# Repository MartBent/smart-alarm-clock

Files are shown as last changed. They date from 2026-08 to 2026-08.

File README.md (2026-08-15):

# Smart Alarm Clock

A bedside alarm clock built from scratch: custom hardware, firmware in Rust on an
ESP32-S3, and a Home Assistant integration. The idea is a plain wood-veneer bar that
stays dark until you touch it, then shows the time glowing through the veneer. It sits
on the network and works with Home Assistant, but it keeps its own time and fires
alarms itself, so it still rings if WiFi or HA goes down.

Right now it runs on a breadboard. The firmware and the HA integration work; the
custom PCB and the veneer enclosure are still ahead.

## Layout

| Path | What it is |
|---|---|
| `software/firmware/` | Rust (esp-idf) firmware for the device. See [software/README.md](software/README.md). |
| `software/homeassistant/` | Home Assistant integration. It now lives in its own HACS repo; this folder is a pointer. See [README](software/homeassistant/README.md). |
| `software/tools/` | `sim_device.py`, a stand-in for the device over REST + SSE. |
| `hardware/` | PCB, enclosure, and the bench parts list + wiring. See [hardware/README.md](hardware/README.md). |
| `docs/` | Design decisions and the reasoning behind them. See [handoff.md](docs/handoff.md). |

## Hardware

An ESP32-S3 drives a monochrome dot-matrix that shows the time behind wood veneer.
Touch is the ESP32-S3's built-in capacitive sensing through a foil pad, which reads
fine through wood. A DS3231 keeps time while the network is down; on the PCB a
supercap backs it up, so there's no coin cell. Sound is a passive buzzer for now. The
whole thing runs off USB-C, no battery.

It's on a breadboard at the moment. The parts list, wiring, and PCB plan are in
[hardware/README.md](hardware/README.md).

## Software

The firmware is a handful of worker threads around one shared state machine. The
alarm core owns the clock and the eight alarm slots and decides when to ring; nothing
about firing depends on the network. There's an on-device web UI with a WiFi captive
portal for first-time setup, and two ways into Home Assistant: MQTT discovery, and a
broker-free integration that uses the REST API with SSE for live updates. A small
Python simulator stands in for the hardware so the HA side can be worked on without a
device.

Build and flash steps, the thread layout, and the HA details are in
[software/README.md](software/README.md).

## Design

The locked decisions and why they were made are in [docs/handoff.md](docs/handoff.md).

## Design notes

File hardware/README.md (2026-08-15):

# Hardware

The custom PCB and enclosure, plus the breadboard bench validation that has to pass
before either gets built. The bench board so far is a YD-ESP32-S3 devkit
(ESP32-S3-WROOM-1). The reasoning behind the design choices is in
[`../docs/handoff.md`](../docs/handoff.md).

## Components (v1)

- MCU: ESP32-S3-WROOM-1 with native USB-JTAG. Bench board is a YD-ESP32-S3 devkit.
- Time: SNTP, with a DS3231 RTC and a supercap for backup. No coin cell.
- Power: USB-C mains, 5 V stepped down to 3.3 V. The supercap only backs the RTC.
- Display: a monochrome dot-matrix showing the time, behind wood veneer, dark when
  idle. The bench uses a red MAX7219 32×8; the final panel will be a warm/amber
  emitter picked at the PCB stage. Status (armed, ringing, and so on) shows on the
  onboard WS2812 RGB LED.
- Interaction: the ESP32-S3's built-in capacitive touch, a foil or copper pad behind
  the veneer with a tap/hold grammar. It reads through wood, which sidesteps the
  IR-through-veneer problem. Rear buttons are available too.
- Audio: a passive buzzer driven by LEDC/PWM through a BS170 low-side switch. Real
  audio is a possible later addition (see below).

## Bench validation

The point of this stage is to get the whole device working on a breadboard before
committing to a PCB. Each part below already has a firmware hook, or is the next
thing to wire. It uses the dev board and buttons already on hand. Sourcing is EU
(Tinytronics, Antratek, AliExpress); the prices are rough guides.

### Parts

Everything came from Tinytronics except the veneer (and, later, the copper tape).

| Part | Serves | Firmware hook | ~€ |
|---|---|---|---|
| **LED Matrix 32×8 with MAX7219** (red, 3-wire SPI-like; SKU 003516) | shows `HH:MM` (time only) — validate 4-digit layout/legibility/geometry behind veneer | matrix time render (to wire) | 6 |
| **Keyestudio DS3231 RTC** module (I²C, SKU 005849) | correct time on boot + offline alarm firing | RTC read/set fallback (scaffolded) | 4 |
| **Passive Buzzer 3-12V — Dupont-Jumper** (passive → PWM tones) | v1 wake sound | LEDC/PWM (`buzzer.rs`) | 1 |
| **4-channel Bi-Directional Logic Level Converter** (3.3↔5 V, BSS138) | reliable data into the 5 V MAX7219 from 3.3 V ESP32 | — | 1.5 |
| **Capacitive-touch electrode** — kitchen foil / jumper (proper copper tape later, *not* at Tinytronics) | tap + hold gestures via the ESP32-S3's **native** touch peripheral, no sensor chip | touch → `Command` bus (to wire) | ~0 |
| **Wood veneer sample pack** (~0.6 mm; walnut/oak/etc.) — *source elsewhere* | display glow-through look **and** capacitive-touch-through-veneer tuning | — | 5–10 |
| Decoupling caps (100 nF / 10 µF) | supporting | — | 2 |
| *Optional:* single **SK6812 / WS2812** discrete pixel | final placement of the RGB status LED (onboard WS2812 covers the bench) | already driven in `led.rs` | 1–2 |
| *Optional:* **Logic Analyzer 8-channel USB** | SPI/I²C bring-up debugging (sigrok/PulseView) | — | 9.75 |

The core is about €12.50 (matrix, RTC, buzzer, level converter), plus roughly €10 for
the optional logic analyzer. It's worth ordering a spare matrix and a spare level
converter. They don't wear out, but a wiring slip in the mixed 3.3/5 V path is easy to
make, and a reorder's shipping and wait cost more than the part does.

Status (2026-07-27): the electronics arrived; the veneer still needs sourcing. The
buzzer firmware is written. Breadboard bring-up was waiting on a soldering iron to
attach the dev-board header.

### Wiring

Every signal lands on the YD-ESP32-S3 power-side header (the `5Vin` / `3V3` / `RST`
row), so one soldered header covers the whole bench. The pin table below is the logical
reference (what connects to what), not a physical breadboard layout. The same
connections, drawn as a schematic, live under
[PCB and enclosure](#pcb-and-enclosure-after-bench-validation).

| Function | Pin | Notes |
|---|---|---|
| Buzzer | `GPIO4` | LEDC PWM → BS170 gate (low-side switch); internal pulldown, no external resistor |
| RTC SDA / SCL | `GPIO8` / `GPIO9` | I²C; **power the DS3231 at 3.3 V** (pull-ups reference VCC); scan should ACK at `0x68` |
| Matrix CS / DIN / CLK | `GPIO10` / `GPIO11` / `GPIO12` | native FSPI pins; **5 V logic** → drive through the level shifter |
| Cap touch | `GPIO14` | foil electrode; **no pull resistor** (interferes with sensing) |
| Power | `5Vin` / `3V3` / `GND` | `5Vin` = USB VBUS (5 V out when USB-powered); matrix VCC on `5Vin`, keep brightness modest |

A few things worth watching:

- Check the BS170's Drain and Source against your part's datasheet. The pinout is
  manufacturer-dependent (BS170 and 2N7000 are mirror images), and swapping D/S is the
  classic "won't switch" bug.
- Avoid `GPIO46` (LOG) and `GPIO3` (JTAG) on that header; both are strapping pins.
- The onboard WS2812 status LED is `GPIO48`, on the opposite header, left free for the
  phase-color LED.
- No loose resistors are needed: the module pull-ups and the BS170's internal gate
  pulldown cover it.
- If capacitive touch feels wrong, the fallback is a GY-APDS-9900 IR-reflective
  proximity module (I²C, about €3.50), which brings the IR-through-veneer test back.

### Bring-up sequence

1. Solder the dev-board header, then bring up the peripherals one at a time: RTC (I²C
   scan → `0x68`), buzzer, MAX7219 `HH:MM` render, capacitive touch. Prove the `HH:MM`
   glow, touch-through-veneer, and the warm look before a PCB.
2. Flesh out the firmware on the breadboard: RTC read, matrix render, touch input and
   tuning, NVS persistence.
3. KiCad schematic → ERC → 2-layer layout → DRC → Gerbers → order.
4. Bring up the bare board incrementally; iterate the veneer enclosure.

### Deferred to the PCB stage (the bench uses the simpler thing)

- RTC backup with a supercap instead of a coin cell. The supercap goes on the DS3231
  VBAT pin (across the coin-cell pads), not VCC — VBAT is the low-power (~1 µA) backup
  input. The DS3231 doesn't charge VBAT, so add a trickle path from VCC:
  `VCC → R (few hundred Ω–1k) → Schottky → supercap → GND`, with the cap rated at or
  above VCC (VBAT tops out at 5.5 V). On the bench, just use the CR1220.
- The warm display emitter. The bench matrix is red; source a warm/amber ~32×8 emitter
  once the veneer test confirms the geometry.

## Future option: real audio / HA media player

The v1 buzzer could later give way to real audio: a default tone stored on the device
for an offline wake sound, user-uploadable sound files, and registering as an HA
`media_player` so HA can push TTS, chimes, or radio. That needs about €20 of extra
parts: an ESP32-S3-DevKitC-1 N16R8 (16 MB flash for uploads and 8 MB PSRAM to
buffer/decode streams, neither of which the current board has), a MAX98357A I²S amp,
and a 3–4 W speaker. Two decisions are still open: WAV vs MP3 for uploads, and Rust vs
ESPHome for the `media_player`. The Rust path is a large firmware lift; ESPHome
provides it natively but would replace the current firmware.

## PCB and enclosure (after bench validation)

- A 2-layer KiCad design: schematic → ERC → layout → DRC → Gerbers → fab (JLCPCB vs
  Aisler in the EU). 0805 passives, module antenna, hand-soldered for v1.
- A wood-veneer bar enclosure: the matrix glows through the veneer, with a concealed
  USB-C port and hidden fasteners.

There are two schematic variants. They differ only in how much is a plug-in module
versus a part on the board. Where to draw that line follows how hard each block is to
make discrete: the RTC and the level shifter are easy, the MAX7219 is more work (a lot
of routing), and the ESP32 is the hard one (its antenna needs careful RF layout).

### Prototype carrier-PCB schematic (the first board to fab)

The [prototype schematic](KiCad/SmartAlarmClock_prototype/) is the board to build first.
It's a carrier. The ESP32-S3 dev board (J1), the MAX7219 matrix (J2), and the DS3231 RTC
module (J3, a ZS-042 with a rechargeable cell, so no disposable battery) all plug in on
headers. The board itself holds only the easy parts: a BSS138 3-channel level shifter
with 10k pull-ups for the matrix's 3.3↔5 V lines, the BS170 buzzer driver, a touch pad
(J4), and decoupling. The two awkward blocks stay as modules for now, the ESP32 and the
MAX7219, because those are the ones worth getting right on a later board. The RTC and
touch run at 3.3 V, so only CS/DIN/CLK cross the shifter. ERC passes with no errors or
warnings.

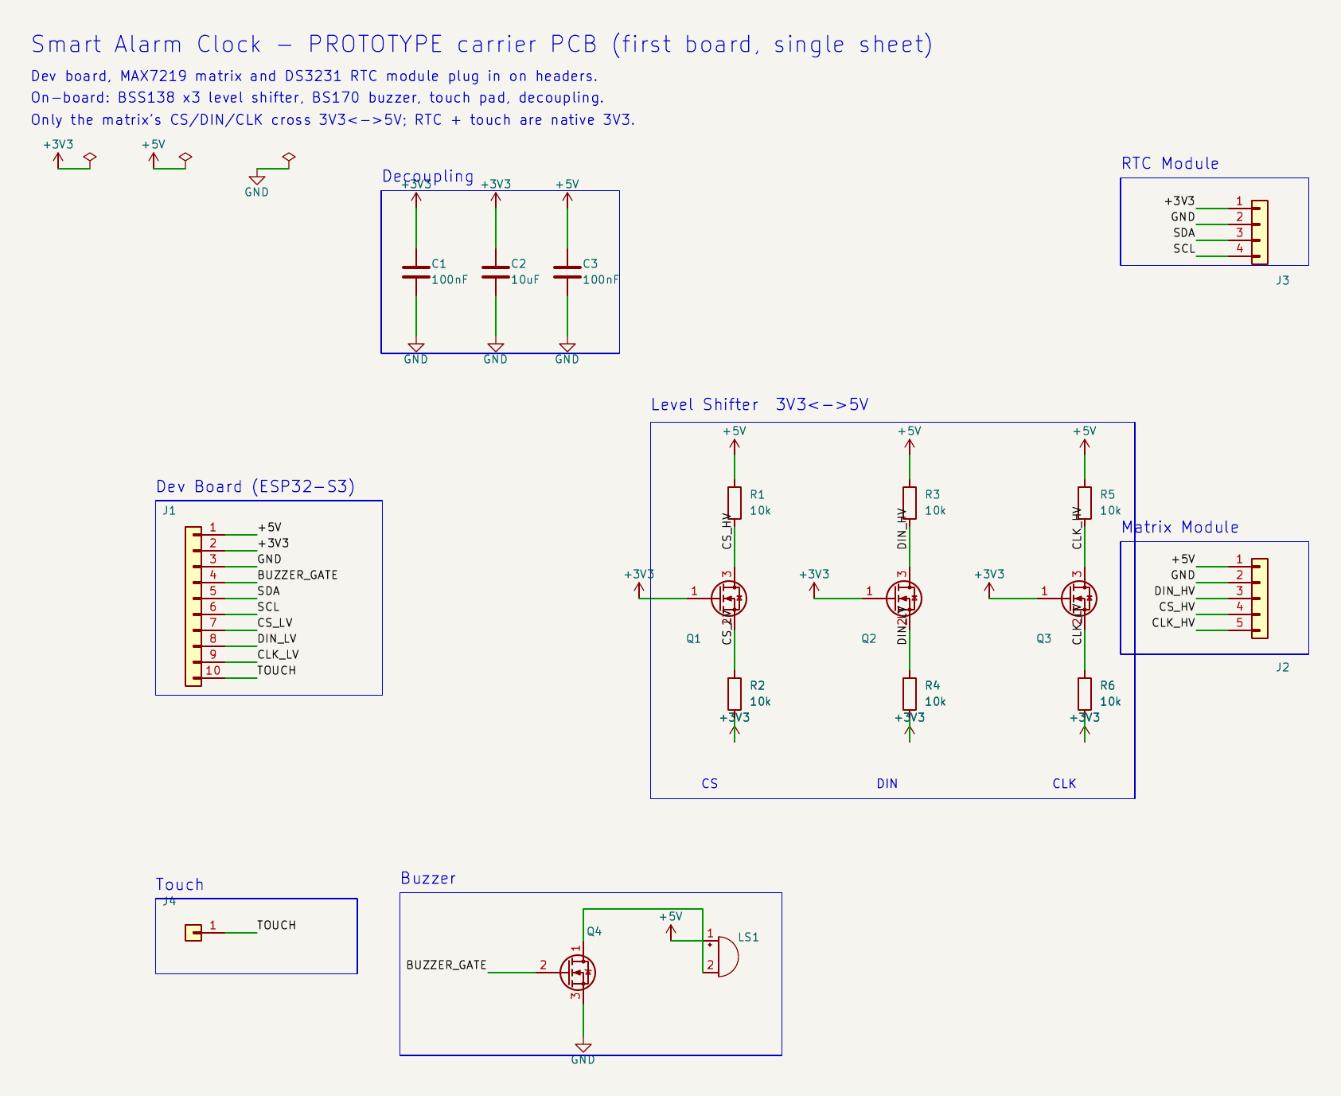
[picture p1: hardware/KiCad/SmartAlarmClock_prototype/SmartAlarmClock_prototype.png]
Prototype carrier-PCB schematic


### Discrete carrier-PCB schematic (a later v2)

The [discrete schematic](KiCad/SmartAlarmClock_discrete/) goes one step further. It also
puts the RTC on the board as a bare DS3231 with a supercap backup, trickle-charged from
`+3V3` through a resistor and a Schottky onto VBAT (no coin cell), and it keeps the level
shifter discrete. The dev board (J1) and MAX7219 matrix (J2) still plug in on headers.
ERC is clean here too. This is where the board goes once the first one works and
soldering an SO-8 RTC by hand feels fine.

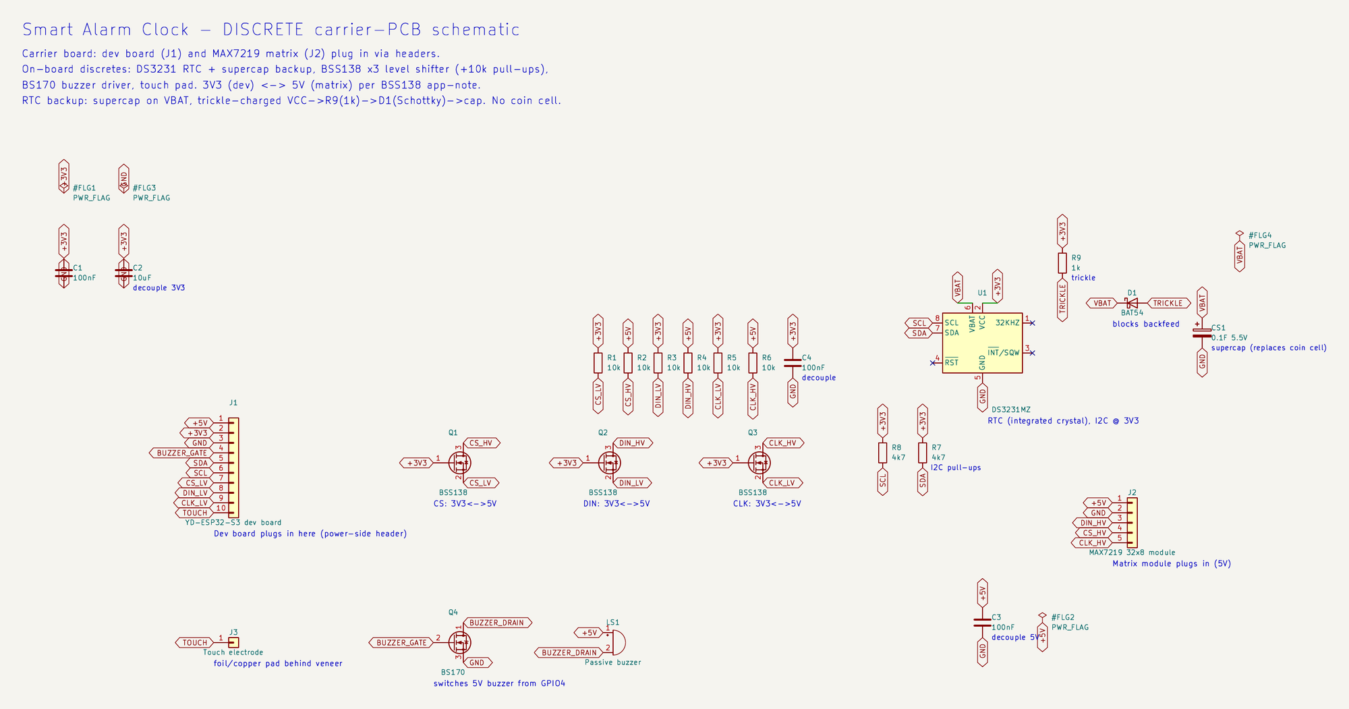
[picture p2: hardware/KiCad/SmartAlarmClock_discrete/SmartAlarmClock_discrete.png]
Discrete carrier-PCB schematic


## Open questions

- Warm display-emitter sourcing (the bench uses red).
- Capacitive-touch-through-veneer tuning: electrode size, thresholds, and behaviour on
  a groundless USB supply.
- Per-slot fields (repeat days, sound, sunrise), which drive the HA entity set and the
  NVS schema.
- Enclosure dimensions; budget and fab (JLCPCB vs Aisler).

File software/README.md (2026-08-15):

# Software

The device firmware plus everything that talks to it off-device.

```
firmware/       Rust (esp-idf) firmware for the ESP32-S3 — the device itself
homeassistant/  Home Assistant custom integration (Python) — see homeassistant/README.md
tools/          sim_device.py — a Python simulator (REST + SSE) for testing HA with no hardware
```

## Firmware

Lives in `firmware/` (entry point `src/main.rs`). `std` path (`esp-idf-hal` + `esp-idf-svc`),
FreeRTOS exposed as `std::thread` — worker threads over shared state behind `Arc<Mutex<…>>`.
Every input (button, REST, MQTT) pushes the same `Command`s onto one bus; the alarm core is the
sole writer.

| Worker | Role |
| --- | --- |
| alarm | **Source of truth** — 8-slot model, state machine, firing, snooze/dismiss. Never blocks on network. |
| net | SoftAP + captive portal, HTTP REST API + web UI, SSE push (:81), mDNS, MQTT discovery/LWT. |
| button | BOOT button → commands. |
| buzzer | Passive buzzer via LEDC — beeps while ringing. |
| led | Onboard WS2812 phase colors (status LED). |

**Alarm model:** a fixed pool of 8 slots (each a time-of-day + `enabled`). Arming is implicit
(armed whenever any slot is enabled); dismiss is one-shot (disables the slot that fired).

Working: alarm core, SNTP wall-clock firing, web UI + captive portal, MQTT + custom HA integration.
Bench TODOs: DS3231 RTC read, MAX7219 time render, capacitive-touch input, NVS persistence.

## Toolchain / build

Xtensa ESP32-S3 on the `std`/esp-idf path — needs the Espressif Rust fork (not stock `rustup`):

```sh
cargo install espup ldproxy espflash cargo-espflash --locked
espup install                 # installs the esp/xtensa toolchain + LLVM
. $HOME/export-esp.sh         # exports env each shell (source it, or add to your profile)
cd firmware
cargo run                     # builds for esp32s3 and flashes over USB-C
```

`firmware/rust-toolchain.toml` pins the `esp` channel; `firmware/.cargo/config.toml` sets the
`xtensa-esp32s3-espidf` target + `espflash flash --monitor` runner, so a plain `cargo run` builds
and flashes. In **RustRover**, the **Flash + monitor** run config (`.run/`) does the same. The
esp-idf build config (`.cargo/config.toml`, `rust-toolchain.toml`, `sdkconfig.defaults`, `build.rs`)
is already included; the first build downloads ESP-IDF `v5.2.3` (slow once, then fast).

> **Flashing won't connect?** (`espflash`: "Error while connecting to device") — almost always a
> **charge-only USB cable**; use a data cable. Sanity-check with `espflash board-info --port <PORT>`
> (this board reports **ESP32-S3**).

## Home Assistant integration

A **broker-free** custom integration (REST + SSE realtime, mDNS discovery, ports 80/81) that adds
the clock to Home Assistant. It lives in its own HACS-installable repo,
**[MartBent/homeassistant-smart-alarm-clock](https://github.com/MartBent/homeassistant-smart-alarm-clock)**
(see [homeassistant/README.md](homeassistant/README.md)). MQTT discovery + LWT is also wired from the
firmware as a second path.

## Simulator

`tools/sim_device.py` (stdlib-only Python) reproduces the device's REST API + SSE stream + state
machine, so the HA integration can be developed and tested with no hardware.

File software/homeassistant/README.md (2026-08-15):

# Home Assistant integration

The custom integration now lives in its own repository so it can be installed
through **HACS** (which requires `custom_components/` at the repo root):

### → [MartBent/homeassistant-smart-alarm-clock](https://github.com/MartBent/homeassistant-smart-alarm-clock)

It's **broker-free**: it talks to the device's local REST API and streams changes
over Server-Sent Events (mDNS discovery, ports 80/81). Install steps, the entity
list, and how it works are in that repo's README.

MQTT discovery + LWT is also wired from the firmware (`../firmware/src/mqtt.rs`)
as a second, broker-based path into Home Assistant.

> Develop/test without hardware using `../tools/sim_device.py`, which reproduces
> the device's REST API + SSE stream + state machine.

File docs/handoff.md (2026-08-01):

# Smart Alarm Clock — Handoff

Context for continuing this project: the locked design, key reasoning, what's built, and what's open.

## In one paragraph
A custom-hardware, embedded-Rust, Home-Assistant-aware bedside **smart alarm clock**. Aesthetic:
**"dark & silent until summoned"** — a wood-veneer bar that shows nothing until a touch reveals the
time glowing *through* the veneer. Integrates with Home Assistant, but fires alarms **on-device** so
it works with WiFi/HA down.

---

## Locked decisions

### Architecture & firmware
- HA-aware but **offline-capable**; alarm firing lives on-device; the device is the **source of truth**.
- **Rust, `std` path** (`esp-idf-hal` + `esp-idf-svc`), FreeRTOS via ESP-IDF exposed as `std::thread`.
  Chosen for the mature WiFi/TLS/MQTT stack (`no_std` WiFi would be a fight).

### MCU & power
- **ESP32-S3-WROOM-1** (native USB-JTAG for program+debug). Bench board: **YD-ESP32-S3** devkit.
- **Time:** SNTP primary + **DS3231 RTC** + **supercap** backup (no battery) — RTC gives correct time
  on boot / when offline; SNTP corrects drift.
- **Power:** USB-C mains only, 5V→3.3V buck. No device battery. Accepted limit: a power cut spanning
  the alarm time misses it (phone is the backstop); the supercap keeps time so there's no blinking 12:00.

### Display
- Monochrome **dot-matrix showing time only**, behind warm wood veneer, **OFF when idle** (true dark).
  Bench: **red MAX7219 32×8** (validates the `HH:MM` layout + glow); final: a **warm/amber** emitter (PCB-stage).
- **Status (armed / ringing / AP / syncing) via a single RGB LED** — already driven on the onboard
  WS2812 with phase colors, so it costs no display space.

### Interaction — native capacitive touch
- **ESP32-S3 native capacitive touch** on a copper/foil electrode behind the veneer. Grammar:
  **tap = reveal/snooze, ~2.5 s hold = dismiss**. Rear buttons available.
- *Why:* capacitive senses **through wood**, which removes the biggest PCB-blocking unknown
  (IR-through-veneer). *(Pivot 2026-07-25 from a VCNL4040 proximity sensor.)* Fallback if touch feels
  wrong: a GY-APDS-9900 IR-reflective proximity module (reintroduces the IR test).

### Audio
- v1: **passive buzzer** via LEDC/PWM on GPIO4, switched by a **BS170** low-side MOSFET off 5 V.
- Future: real audio — default tone on device + user-uploadable files + registering as an HA
  `media_player` — needs a PSRAM board (N16R8) + MAX98357A + speaker. Open: WAV vs MP3, Rust vs
  ESPHome. See [Hardware → Future option](../hardware/README.md#future-option--real-audio--ha-media-player).

### Alarm model
- **Fixed pool of 8 slots** (`NUM_PRESETS` in `../software/firmware/src/state.rs`), each a time-of-day
  + `enabled`. (Repeat-days / sound / sunrise are future per-slot fields.)
- **Implicit arming:** `Armed` whenever any slot is enabled, else `Idle` — no arm/disarm control.
- **Dismiss is one-shot:** dismissing disables the slot that fired. Snooze re-rings after the interval.

### Config & HA integration
- **Setup:** first boot / WiFi change / recovery → WiFi **AP + captive portal** (self-contained).
  Everyday: **mDNS `.local`** web UI. Settings persisted in **NVS**.
- **HA — two paths, both wired:** (1) **MQTT discovery + LWT**; (2) a **custom integration** (REST +
  **SSE** realtime, **ports 80/81**, mDNS discovery, no broker required). Dashboards / automations /
  theme live in the `home-lab` repo; this repo owns only the integration.
- **Source-of-truth rule:** the device owns state; local actions and HA commands are both inputs to
  one on-device state machine; offline → local control unaffected, resync on reconnect.

### PCB & enclosure
- 2-layer KiCad, 0805 passives, module's onboard antenna, hand-soldered v1. Fab TBD (JLCPCB vs Aisler EU).
- Bedside landscape **wood-veneer bar**; matrix glows through the veneer; concealed USB-C; hidden fasteners.

---

## Firmware (current)
Real firmware + a working HA integration exist (past the scaffold stage). Code: `../software/firmware/`.
Worker threads (each a `std::thread`; the alarm core never blocks on the network):

- **alarm** — source of truth: 8-slot model + state machine + command bus; SNTP wall-clock firing.
- **net** — SoftAP + captive portal, HTTP REST API + web UI, SSE push (:81), mDNS, MQTT discovery/LWT.
- **button** — BOOT button → commands.
- **buzzer** — passive buzzer via LEDC (beeps while ringing).
- **led** — onboard WS2812 phase colors (status LED).

Every input transport (button, REST, MQTT) pushes the same `Command`s onto one bus.

**Not yet wired (bench tasks):** DS3231 RTC read (SNTP works; RTC boot-fallback scaffolded), MAX7219
time render, capacitive-touch input + tuning, NVS persistence of slots/settings.

**Toolchain:** `espup` (Xtensa S3 fork) → from `software/firmware/`, `cargo run` builds + flashes over USB-C.

---

## Bench validation (gates the PCB)
Parts, wiring, and rationale: [Hardware → Bench validation](../hardware/README.md#bench-validation).

1. **Bench-validate on a breadboard (~€30–55, ordered):** existing dev-kit + MAX7219 32×8 (time) +
   DS3231 + buzzer/BS170 + level converter + foil touch electrode + wood veneer samples. Prove the
   `HH:MM` glow, capacitive-touch-through-veneer, and the warm look before a PCB.
2. Flesh out firmware on the breadboard: RTC read, matrix render, touch input + tuning, NVS.
3. KiCad schematic → ERC → 2-layer layout → DRC → Gerbers → order.
4. Bring up the bare board incrementally; iterate the veneer enclosure.

**Status (2026-07-27):** parts arrived (veneer pending); buzzer firmware written; waiting on a
soldering iron to attach the dev-board header before breadboard bring-up.

---

## Open questions
- Warm display-emitter sourcing (bench uses red).
- Capacitive-touch-through-veneer tuning (electrode size, thresholds, groundless USB supply).
- Per-slot fields (repeat days / sound / sunrise) → drives the HA entity set + NVS schema.
- Enclosure dimensions; budget + fab (JLCPCB vs Aisler).

## v2 / stretch (leave hooks on v1)
Real audio / HA `media_player` (above); haptic dismiss (LRA + DRV2605L); sunrise light-ramp; BME280
climate (or the on-hand DS18B20); NFC preset tokens; broker-free HA (ESPHome-native / HomeKit).

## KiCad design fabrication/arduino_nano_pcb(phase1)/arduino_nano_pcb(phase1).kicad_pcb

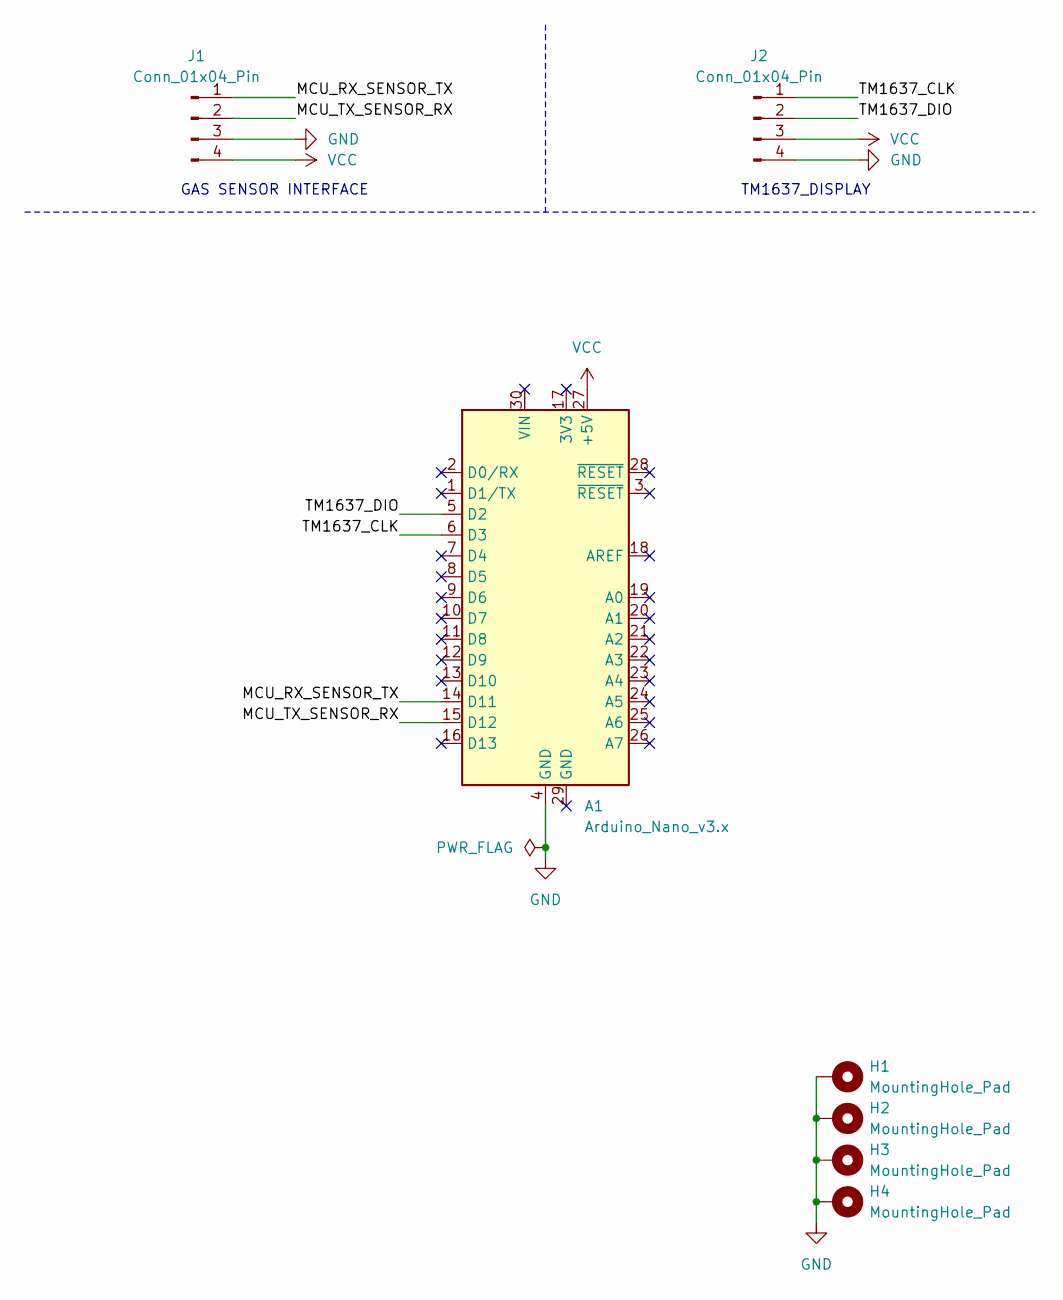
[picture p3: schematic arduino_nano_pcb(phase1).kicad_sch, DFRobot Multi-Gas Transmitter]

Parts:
A1: Arduino_Nano_v3.x; Arduino_Nano
H1, H2, H3, H4: MountingHole_Pad; MountingHole_5mm_Pad_TopBottom
J1: Conn_01x04_Pin; PinHeader_1x04_P2.54mm_Horizontal
J2: Conn_01x04_Pin; TM1637

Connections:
/MCU_RX_SENSOR_TX: A1.14 (D11), J1.1
/MCU_TX_SENSOR_RX: A1.15 (D12), J1.2
/TM1637_CLK: A1.6 (D3), J2.1
/TM1637_DIO: A1.5 (D2), J2.2
GND: A1.4 (GND), H1.1 (1_1), H2.1 (1_1), H3.1 (1_1), H4.1 (1_1), J1.3, J2.4
VCC: A1.27 (+5V), J1.4, J2.3

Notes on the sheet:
TM1637_DISPLAY
GAS SENSOR INTERFACE

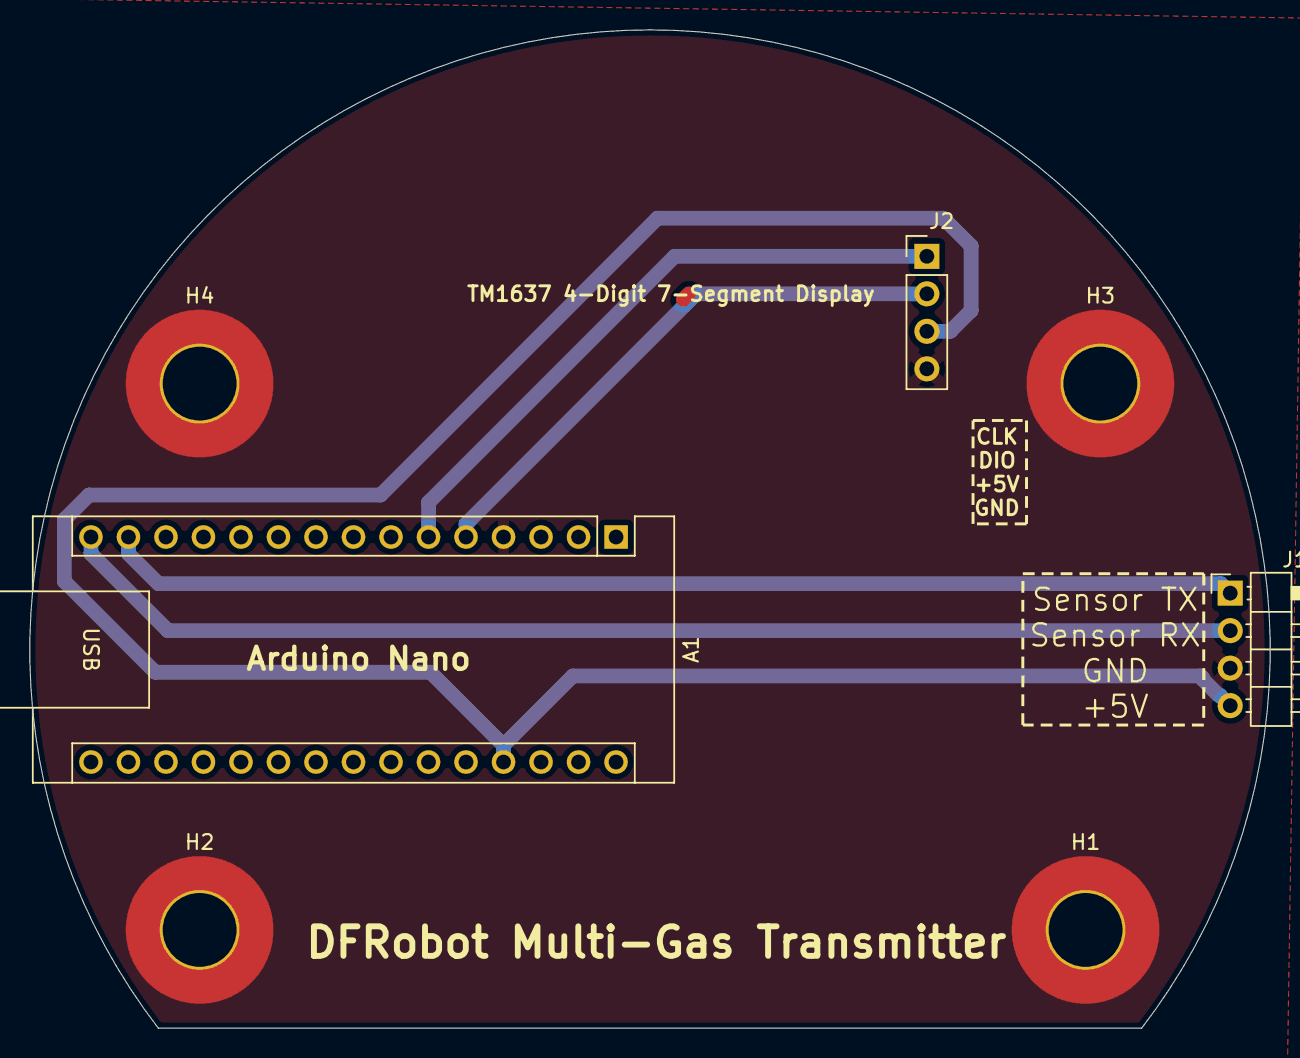
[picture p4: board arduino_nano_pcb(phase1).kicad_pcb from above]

Board: 2 copper layers, 84.0 x 67.6 mm, 7 parts (0 on the bottom side), 6 nets.

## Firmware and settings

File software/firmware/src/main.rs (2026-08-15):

//! Smart alarm clock — ESP32-S3 (esp-idf std).
//!
//! Worker-thread architecture (each subsystem is a `std::thread` / FreeRTOS
//! task). `main` takes the peripherals, builds the shared state + command bus,
//! spawns the workers, and supervises.
//!
//!   alarm   — source of truth: state machine + presets (drains the command bus)
//!   button  — BOOT button -> commands
//!   led     — renders the current phase on the onboard WS2812
//!   display — draws the time as HH:MM on the MAX7219 32x8 matrix (SPI)
//!   buzzer  — passive buzzer (LEDC/PWM on GPIO4): plays the melody while ringing
//!   rtc     — DS3231 (I2C): seeds the clock at boot, persists SNTP time back
//!   net     — SoftAP + HTTP REST API -> commands + state
//!
//! Every input transport (button + REST now; MQTT/HA later) submits the same
//! `Command`s onto the bus. See docs/handoff.md for the design.

mod alarm;
mod button;
mod buzzer;
mod display;
mod dns;
mod led;
mod mqtt;
mod net;
mod rtc;
mod state;

use std::thread::Builder;

use esp_idf_hal::peripherals::Peripherals;
use esp_idf_svc::log::EspLogger;

fn main() {
    // Required once at startup on the esp-idf std path.
    esp_idf_sys::link_patches();
    // Route the `log` crate to the ESP-IDF logger (levels, tags, timestamps).
    EspLogger::initialize_default();

    // Local timezone (Europe/Amsterdam) so localtime() gives wall-clock time
    // with DST once SNTP has set the system clock. TODO: make configurable.
    std::env::set_var("TZ", "CET-1CEST,M3.5.0,M10.5.0/3");
    unsafe { esp_idf_sys::tzset() };

    log::info!(target: "main", "smart-alarm-clock booting");

    let peripherals = Peripherals::take().expect("take peripherals");
    let shared = state::new_shared();
    let bus = state::new_bus();

    // RTC worker (DS3231 over I2C: SDA=GPIO8, SCL=GPIO9). Spawned first so it can
    // seed the system clock from the RTC before the other workers read the time.
    {
        let i2c0 = peripherals.i2c0;
        let sda = peripherals.pins.gpio8;
        let scl = peripherals.pins.gpio9;
        Builder::new()
            .name("rtc".into())
            .stack_size(4 * 1024)
            .spawn(move || rtc::run(i2c0, sda, scl))
            .expect("spawn rtc worker");
    }

    // Alarm core (source of truth) — drains the command bus.
    {
        let shared = shared.clone();
        let bus = bus.clone();
        Builder::new()
            .name("alarm".into())
            .stack_size(8 * 1024)
            .spawn(move || alarm::run(bus, shared))
            .expect("spawn alarm worker");
    }

    // BOOT-button transport.
    {
        let bus = bus.clone();
        let pin = peripherals.pins.gpio0;
        Builder::new()
            .name("button".into())
            .stack_size(4 * 1024)
            .spawn(move || button::run(pin, bus))
            .expect("spawn button worker");
    }

    // LED (display) worker.
    {
        let shared = shared.clone();
        let channel = peripherals.rmt.channel0;
        let pin = peripherals.pins.gpio48;
        Builder::new()
            .name("led".into())
            .stack_size(8 * 1024)
            .spawn(move || led::run(channel, pin, shared))
            .expect("spawn led worker");
    }

    // Matrix display worker — draws the time as HH:MM on the MAX7219 32x8 panel
    // (SPI2: SCLK=GPIO12, DIN=GPIO11, CS=GPIO10, via the level shifter).
    {
        let shared = shared.clone();
        let spi = peripherals.spi2;
        let sclk = peripherals.pins.gpio12;
        let din = peripherals.pins.gpio11;
        let cs = peripherals.pins.gpio10;
        Builder::new()
            .name("display".into())
            .stack_size(8 * 1024)
            .spawn(move || display::run(spi, sclk, din, cs, shared))
            .expect("spawn display worker");
    }

    // Buzzer worker — passive buzzer via LEDC/PWM on GPIO4 (plays melody while ringing).
    {
        let shared = shared.clone();
        let timer = peripherals.ledc.timer0;
        let channel = peripherals.ledc.channel0;
        let pin = peripherals.pins.gpio4;
        Builder::new()
            .name("buzzer".into())
            .stack_size(4 * 1024)
            .spawn(move || buzzer::run(timer, channel, pin, shared))
            .expect("spawn buzzer worker");
    }

    // Network worker — SoftAP + HTTP REST API.
    {
        let shared = shared.clone();
        let bus = bus.clone();
        let modem = peripherals.modem;
        Builder::new()
            .name("net".into())
            .stack_size(16 * 1024)
            .spawn(move || net::run(modem, shared, bus))
            .expect("spawn net worker");
    }

    log::info!(target: "main", "workers spawned");

    // Supervisor: stay alive so the workers keep running.
    loop {
        std::thread::sleep(std::time::Duration::from_secs(60));
    }
}

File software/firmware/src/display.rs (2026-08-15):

//! Matrix display worker — draws the current time as HH:MM on the MAX7219 32x8
//! panel (4x cascaded 8x8 modules, SPI). Reads shared state each frame; the
//! alarm core is the sole writer of the clock. Renders a blinking `--:--` while
//! [`Phase::Syncing`] (before SNTP has set the clock), then the real wall-clock
//! time with a ~0.5 Hz blinking colon.
//!
//! Hardware (via the level shifter, per hardware/README.md):
//!   SCLK=GPIO12  DIN=GPIO11  CS=GPIO10 ; matrix VCC=5V, common GND.
//!
//! FC-16 modules are physically rotated, so the flush maps each MAX7219 "digit"
//! register to a ROW (its 8 bits are that chip's 8 columns). If a rebuild looks
//! mirrored / upside-down / module-swapped, flip the orientation knobs below
//! rather than re-deriving the mapping.

use core::time::Duration;

use esp_idf_hal::gpio::{AnyIOPin, Gpio10, Gpio11, Gpio12};
use esp_idf_hal::spi::config::{Config as SpiConfig, DriverConfig};
use esp_idf_hal::spi::{SpiDeviceDriver, SpiDriver, SPI2};
use esp_idf_hal::units::FromValueType;

use crate::state::{Phase, SharedState};

const CHIPS: usize = 4;
const W: usize = CHIPS * 8; // 32 columns
const H: usize = 8;

// --- orientation knobs (flip these if the display looks wrong) ---
const REVERSE_MODULES: bool = true; // which chip is the leftmost 8 columns
const FLIP_X: bool = false; // column bit-order within a chip (mirror left/right)
const FLIP_ROWS: bool = false; // top vs bottom row = digit register 1 (mirror up/down)
const BRIGHTNESS: u8 = 0x02; // 0x00..=0x0F

/// Left edge of each of the four HH:MM digits (columns), and the colon column.
const DIGIT_X: [usize; 4] = [5, 10, 19, 24];
const COLON_X: usize = 15;

const FRAME: Duration = Duration::from_millis(200);

type Fb = [[bool; W]; H];

// 3x5 digit font — 5 rows, low 3 bits each (bit2 = leftmost column).
const FONT: [[u8; 5]; 10] = [
    [0b111, 0b101, 0b101, 0b101, 0b111], // 0
    [0b010, 0b110, 0b010, 0b010, 0b111], // 1
    [0b111, 0b001, 0b111, 0b100, 0b111], // 2
    [0b111, 0b001, 0b111, 0b001, 0b111], // 3
    [0b101, 0b101, 0b111, 0b001, 0b001], // 4
    [0b111, 0b100, 0b111, 0b001, 0b111], // 5
    [0b111, 0b100, 0b111, 0b101, 0b111], // 6
    [0b111, 0b001, 0b001, 0b001, 0b001], // 7
    [0b111, 0b101, 0b111, 0b101, 0b111], // 8
    [0b111, 0b101, 0b111, 0b001, 0b111], // 9
];

/// A 4-module MAX7219 matrix: owns the SPI link and an off-screen framebuffer.
/// Draw into the framebuffer, then [`flush`](Matrix::flush) it to the panel.
pub struct Matrix {
    spi: SpiDeviceDriver<'static, SpiDriver<'static>>,
    fb: Fb,
}

impl Matrix {
    /// Take SPI2 + the three matrix pins and bring the panel up (out of test/
    /// shutdown, raw segments, all rows scanned, at [`BRIGHTNESS`]).
    pub fn new(spi: SPI2, sclk: Gpio12, din: Gpio11, cs: Gpio10) -> Self {
        let mut spi = SpiDeviceDriver::new_single(
            spi,
            sclk,
            din,
            Option::<AnyIOPin>::None, // SDI / MISO — unused
            Some(cs),
            &DriverConfig::new(),
            &SpiConfig::new().baudrate(1u32.MHz().into()),
        )
        .expect("matrix SPI init");

        // Init sequence, broadcast to all 4 chips.
        for (reg, val) in [
            (0x0F, 0x00),      // display-test off
            (0x09, 0x00),      // no BCD decode (raw segments)
            (0x0B, 0x07),      // scan all 8 rows
            (0x0A, BRIGHTNESS), // intensity
            (0x0C, 0x01),      // normal operation (out of shutdown)
        ] {
            spi.write(&broadcast(reg, val)).ok();
        }

        Self { spi, fb: [[false; W]; H] }
    }

    /// Power the panel on (normal operation) or off (shutdown — LEDs dark, no
    /// current). Send only on a state change to avoid needless traffic.
    pub fn set_power(&mut self, on: bool) {
        self.spi.write(&broadcast(0x0C, if on { 0x01 } else { 0x00 })).ok();
    }

    fn clear(&mut self) {
        self.fb = [[false; W]; H];
    }

    /// Draw one 3x5 digit with its left column at `x0` (glyph sits in rows 1..=5).
    fn draw_digit(&mut self, digit: usize, x0: usize) {
        const Y0: usize = 1;
        for (r, bits) in FONT[digit].iter().enumerate() {
            for col in 0..3 {
                if bits & (1 << (2 - col)) != 0 {
                    self.fb[Y0 + r][x0 + col] = true;
                }
            }
        }
    }

    /// Compose HH:MM into the framebuffer; `colon` toggles the two colon dots.
    pub fn render_time(&mut self, hh: u32, mm: u32, colon: bool) {
        self.clear();
        self.draw_digit((hh / 10) as usize, DIGIT_X[0]);
        self.draw_digit((hh % 10) as usize, DIGIT_X[1]);
        self.draw_digit((mm / 10) as usize, DIGIT_X[2]);
        self.draw_digit((mm % 10) as usize, DIGIT_X[3]);
        if colon {
            self.fb[2][COLON_X] = true;
            self.fb[4][COLON_X] = true;
        }
    }

    /// Compose a blinking `--:--` placeholder shown until the clock is synced.
    pub fn render_syncing(&mut self, on: bool) {
        self.clear();
        if on {
            for x0 in DIGIT_X {
                for col in 0..3 {
                    self.fb[3][x0 + col] = true; // dash at mid-row
                }
            }
            self.fb[2][COLON_X] = true;
            self.fb[4][COLON_X] = true;
        }
    }

    /// Push the framebuffer to the four chips. Each digit register is a ROW; its
    /// 8 bits are that chip's 8 columns (FC-16 modules are rotated 90°).
    pub fn flush(&mut self) {
        for y in 0..H {
            let dreg = (if FLIP_ROWS { H - y } else { y + 1 }) as u8;
            let mut f = [0u8; CHIPS * 2];
            // First pair clocked in lands in the farthest chip → send pos high→low.
            for (i, pos) in (0..CHIPS).rev().enumerate() {
                let dc = if REVERSE_MODULES { CHIPS - 1 - pos } else { pos };
                let mut b = 0u8;
                for cx in 0..8usize {
                    let x = dc * 8 + cx;
                    if self.fb[y][x] {
                        let bit = if FLIP_X { cx } else { 7 - cx };
                        b |= 1 << bit;
                    }
                }
                f[i * 2] = dreg;
                f[i * 2 + 1] = b;
            }
            self.spi.write(&f).ok();
        }
    }
}

/// A register command `{reg, val}` broadcast to all 4 cascaded chips.
fn broadcast(reg: u8, val: u8) -> [u8; CHIPS * 2] {
    let mut f = [0u8; CHIPS * 2];
    for i in 0..CHIPS {
        f[i * 2] = reg;
        f[i * 2 + 1] = val;
    }
    f
}
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

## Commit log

2026-06-30 Scaffold smart alarm clock firmware (light skeleton)
    Initial ESP32-S3 / embedded-Rust (std, esp-idf) skeleton for the
    HA-aware, offline-capable bedside smart alarm clock.
    Lays out the four-thread structure from the design handoff as stubs
    with TODOs, leaving all core logic for the project owner to write:
    - src/main.rs boot + four-thread spawn sketch
    - src/state.rs source-of-truth shared state (preset model / state machine / settings)
    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
2026-07-09 Add ESP32 (TTGO T-Display) target alongside ESP32-S3
    - .cargo/config.toml: build-ttgo/run-ttgo aliases + xtensa-esp32-espidf target
    - .run: RustRover Flash config for the classic-ESP32 TTGO board
    - README: TTGO dual-target usage + flashing troubleshooting (data cable / ESP32-S3)
2026-07-21 Slice C: rainbow the onboard WS2812 RGB LED (esp-idf-hal warm-up)
    - Cargo.toml: align on esp-idf-sys 0.36 / esp-idf-hal 0.45; add
    ws2812-esp32-rmt-driver (smart-leds-trait) + smart-leds.
    - .cargo/config.toml: drop the main;pthread component trim so the RMT
    driver component links (and future I2C/SPI/LEDC/WiFi drivers).
    - main.rs: drive onboard WS2812 (GPIO48) via RMT ch0, hsv hue sweep.
    Verified on hardware: boots and runs the rainbow.
2026-07-21 Move rainbow LED driving into a dedicated worker thread
    First worker in the FreeRTOS std::thread architecture: main takes the
    peripherals and spawns led::run (owns RMT ch0 + GPIO48) on its own task.
    Validates the threading model before adding the alarm-core and WiFi workers.
    Verified on hardware: '[led] worker started' prints from the spawned task.
2026-07-21 Slice A: alarm core state machine + command bus + tagged logging
    - state.rs: Phase/Settings/Shared + transport-agnostic Command bus.
    - alarm.rs: source-of-truth worker — Idle/Armed/Ringing/Snoozed state
    machine, stand-in clock (real SNTP time comes in the WiFi slice).
    - button.rs: BOOT (GPIO0) worker — short=snooze, hold=dismiss; first
    command transport.
    - led.rs: renders phase (idle rainbow / armed green / ringing red flash /
    snoozed amber).
    - Switch println! -> log crate + esp-idf-svc EspLogger (levels/tags).
    Verified on hardware: auto-arms, fires after 5s, tagged logs stream.
    [button.rs, led.rs, main.rs]
2026-07-21 Slice D: presets + SoftAP + HTTP REST API
    - state.rs: alarm presets (label/time/enabled) + switch command bus to
    Arc<Mutex<VecDeque>> so HTTP handlers (Send+Sync) can submit commands.
    - alarm.rs: fire by edge-crossing an enabled preset's time (generalizes to
    real SNTP time); apply preset enable/time commands.
    - net.rs: SoftAP + EspHttpServer; JSON REST endpoints (GET /api/state,
    /api/presets; POST /api/command, /api/preset/enabled, /api/preset/time)
    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
2026-07-21 Open SoftAP + captive portal for WiFi provisioning
    - Open AP (no password) when unprovisioned; NVS-driven boot flow: saved
    STA creds -> join network, else setup AP + captive portal.
    - dns.rs: DNS hijack (UDP:53 -> 192.168.71.1) + AP DHCP advertises us as
    DNS (raw esp_netif FFI) so the OS shows the setup sheet.
    - Config page served for / and OS detection URLs; POST /api/wifi saves
    creds to NVS and reboots into STA.
    - REST API (state/command/presets) available in both modes.
    Verified on hardware: open AP + DNS + DHCP-DNS + HTTP server all boot.
    Provisioning UX (popup + join) pending on-device test.
    [main.rs]
2026-07-21 Serve control WebUI at / in STA mode; setup form only in AP mode
    Bug: / (and OS-detection URLs) served the WiFi-setup page unconditionally,
    so a connected device showed 'Connect the clock to your WiFi' instead of a
    control page. Now register() is mode-aware: AP mode -> setup/captive-portal
    pages; STA mode -> a control WebUI (status + arm/snooze/dismiss + preset
    enable/time) that drives the REST API.
    Also: correct DHCP-DNS setup order (offer before dns info) + return-code
    logging, and DNS query logging (from earlier captive-portal debugging).
    Verified over LAN: GET / is the control page; POST /api/command dismiss
    moves phase ringing -> armed.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
2026-07-21 Polish web UI: dark-ember styling + fix polling focus-clobber
    - Shared inline stylesheet (system fonts, no external assets): dark warm
    background, amber 'glow' accent, tabular-monospace clock with a soft glow
    as the signature — matches the 'dark & silent until summoned' aesthetic.
    Setup + control pages share it via a __STYLE__ placeholder.
    - Control page: custom toggle switches for presets, primary Dismiss button.
    - Fix: the 1s poll rebuilt preset inputs every tick, stealing focus while
    typing. Now it only rebuilds when presets change AND nothing is focused.
    Verified over LAN: styled page served; time/phase update live without
    clobbering input.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
2026-07-21 Slice B: SNTP real time; alarm fires on real wall-clock
    - net.rs: start EspSntp in STA mode (syncs system clock via pool.ntp.org).
    - main.rs: set TZ (Europe/Amsterdam) + tzset so localtime() is wall-clock.
    - alarm.rs: retire the stand-in clock; read real local time via
    time()/localtime_r. New Phase::Syncing until the clock is valid, then
    auto-arm; presets fire by edge-crossing real local time.
    - state.rs/led.rs: Phase::Syncing (dim blue on the LED).
    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
2026-07-21 MQTT + Home Assistant integration + WiFi reset endpoint
    - mqtt.rs: new worker (STA mode). Connects to a broker with LWT availability,
    publishes HA MQTT-discovery for phase sensor / Armed switch / Snooze+Dismiss
    buttons / per-preset enable switches, publishes retained state on change,
    and subscribes to command topics -> the shared command bus (same core the
    button + REST drive). Another transport, no core changes.
    - net.rs: broker config in NVS + POST /api/mqtt (+ web UI form) -> reboot to
    connect; spawn the mqtt worker in STA mode when configured.
    - net.rs: POST /api/wifi/reset clears creds -> reboots into the setup AP.
    - main.rs: mod mqtt.
    Verified against a public broker (paho):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
    [main.rs]
2026-07-22 Enable mDNS + add Home Assistant custom integration
    Firmware:
    - Cargo.toml: pull in the espressif/mdns managed component so
    esp_idf_svc::mdns compiles; net.rs advertises smart-alarm-clock.local +
    a _smartalarm._tcp service (TXT sse=81) for HA Zeroconf discovery.
    Home Assistant integration (homeassistant/custom_components/smart_alarm_clock):
    - Broker-free: talks to the device REST API, instant updates via the SSE
    push endpoint (iot_class local_push), 60s polling fallback.
    - Config flow with Zeroconf auto-discovery + manual host entry.
    - Entities (one HA device): Phase sensor, Armed switch, Snooze/Dismiss
    buttons, per-preset enable switches, per-preset time entities.
    Firmware builds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
2026-07-22 Fix code-review findings: HA identity, SSE, arm intent, preset seconds
    Addresses five issues from review of the July 21-22 work:
    - HA config entry survived neither DHCP changes nor manual+discovery dedup
    because unique_id was the raw host/IP. Firmware now exposes a stable "id"
    (base MAC) in /api/state; config_flow uses it as unique_id and refreshes
    CONF_HOST via _abort_if_unique_id_configured(updates=...).
    - SSE server (:81) served only one client at a time (serve_sse never returns).
    Now spawns a bounded thread per client (MAX_SSE_CLIENTS) with a live counter.
    - arm/disarm issued during Phase::Syncing was silently dropped and the HA
    switch reverted. Intent is now recorded (desired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
2026-07-25 Rework alarm model: 8 fixed slots, implicit arming, /api/alarms; add simulator
    Firmware (state.rs, alarm.rs, net.rs, mqtt.rs):
    - Alarm model is now a fixed pool of NUM_PRESETS=8 slots (time + enabled),
    replacing the 3 named presets; slot index is the stable id.
    - No explicit arm/disarm — the clock is Armed whenever any slot is enabled,
    else Idle. Dismiss disables the slot that fired (one-shot). Removed the
    Arm/Disarm commands, web-UI buttons, and MQTT Armed switch.
    - REST API renamed preset(s) -> alarms: /api/alarms, /api/alarm/enabled,
    /api/alarm/time; /api/state list key is "alarms".
    HA integration:
    - Match the 8-slot / alarms model; remove the Armed switch; add a Time sensor.
    -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
2026-07-25 Move HA dashboards & theme out to home-lab
    The Home Assistant dashboards, automations, and the household theme are
    HA configuration, not part of this device repo — they now live in
    MartBent/home-lab under homeassistant/. This repo keeps only the custom
    integration; the README points to home-lab for the rest.
2026-07-25 docs: add bench-BOM + capacitive-touch/audio pivots
    Add docs/bench-bom.md (the Tinytronics bench-validation parts list,
    ordered) and link it from handoff.md. Capture this session's hardware
    decisions: native ESP32-S3 capacitive touch instead of a proximity
    sensor (removes the IR-through-veneer PCB blocker), time-only display
    with a single RGB status LED, buzzer for v1 with the HA media_player
    deferred as a documented future option, and the supercap-on-VBAT RTC
    backup as a PCB-stage note.
2026-07-25 Restructure into software/{firmware,homeassistant,tools} + hardware/
    Move the Rust firmware crate to software/firmware/ (as a self-contained
    unit: .cargo/, Cargo.*, build.rs, rust-toolchain.toml, sdkconfig.defaults,
    src/), the HA custom integration to software/homeassistant/, and the
    device simulator to software/tools/. Add hardware/ (PCB + enclosure)
    with a placeholder README.
    Repoint .run/ RustRover working dirs to software/firmware, update
    .gitignore anchored paths, add a repo-layout section to the README, and
    fix path references across README + docs + the simulator header.
    [button.rs, led.rs, main.rs]
2026-08-01 Add buzzer worker: passive buzzer via LEDC PWM on GPIO4
    New buzzer.rs worker (shaped like led.rs): drives a passive buzzer on
    GPIO4 via LEDC, beeping ~3 Hz while Ringing and silent otherwise. Tone
    fixed at 2 kHz (the buzzer's resonance); per-note RTTTL deferred (needs a
    mutable-timer restructure). Enables the internal pulldown on GPIO4 to
    hold the BS170 gate low. Wired into main.rs (mod + worker-list doc +
    thread spawn with ledc.timer0/channel0 + gpio4).
    Verified: cargo build clean (esp32s3 target).
    [buzzer.rs, main.rs]
2026-08-01 docs(hardware): add high-level bench wiring diagram (Mermaid)
    hardware/bench-wiring.md — logical what-connects-to-what for the
    breadboard bench: buzzer (BS170 low-side switch on GPIO4), DS3231 RTC
    (I2C at 3.3V), MAX7219 32x8 via level shifter, and the cap-touch
    electrode — all on the YD-ESP32-S3 power-side header. Includes the pin
    plan and wiring gotchas.
2026-08-01 docs: add bench wiring diagram to README
    Embed the high-level Mermaid bench-wiring diagram in the README (renders
    on GitHub) with a link to hardware/bench-wiring.md for the full pin plan.
2026-08-01 docs: bring all .md files up to current state, factual-only
    Update README + handoff to the current design: native capacitive touch
    (dropped VCNL4040), time-only MAX7219 display + RGB-LED status, buzzer
    (BS170/LEDC), 8-slot implicit-arming alarm model, real worker threads
    (alarm/net/button/buzzer/led), and the current bench status. Trim the
    handoff (205 -> 110 lines) and remove way-of-working / working-preference
    content from all docs.
2026-08-01 docs: merge bench-bom into README, drop docs/bench-bom.md
    Fold the bench BOM (parts, wiring notes, bring-up sequence, PCB-stage
    deferrals, future-audio option) into a single README "Bench validation"
    section, and fix the still-stale build sequence + open questions there.
    Redirect all bench-bom.md links (handoff, hardware/README, bench-wiring)
    to the README sections.
2026-08-01 docs: land the README merge content + redirect bench-bom links
    Completes b7f3e9d (which only staged the deletion): the actual
    bench-bom content merged into the README "Bench validation" section,
    the corrected build sequence + open questions, and the redirected
    links in handoff / hardware docs.
2026-08-01 docs: split READMEs — root overview, software/ and hardware/ details
    Root README is now a concise software+hardware overview that points into
    each area. Firmware architecture + toolchain/build + HA + simulator moved
    to a new software/README.md. Hardware components + bench BOM + wiring +
    bring-up + PCB plan + future-audio moved to hardware/README.md. Cross-
    links (handoff, bench-wiring) updated to the new anchor locations.
2026-08-01 docs(hardware): merge bench-wiring.md into hardware/README.md
    Fold the wiring diagram + pin plan into the hardware README's Bench
    validation > Wiring section and drop the separate bench-wiring.md.
    Repoint the handoff wiring link.
2026-08-01 Remove TTGO T-Display support
    Drop the classic-ESP32 (TTGO T-Display) build: remove the build-ttgo/
    run-ttgo cargo aliases and the xtensa-esp32-espidf target from
    .cargo/config.toml, and the TTGO mentions in the docs. (The RustRover
    run config was already removed.) Target is ESP32-S3 only.
2026-08-01 hardware: add hybrid KiCad schematic + render, replace mermaid in README
    Add a high-level block schematic for the bench design (SmartAlarmClock.kicad_sch):
    real KiCad library symbols for the ESP32-S3-WROOM-1, BS170, buzzer and caps;
    DS3231 / MAX7219 / BSS138 level-shifter breakouts as module blocks (stock libs
    only carry the bare chips). Nets joined by global labels; PWR_FLAGs on the rails.
    ERC: 0 errors.
    Render the schematic to SmartAlarmClock.png and embed it in hardware/README.md
    in place of the mermaid bench-wiring diagram. Add a KiCad .gitignore for lock /
    per-user / editor files.
    [SmartAlarmClock.kicad_pcb, SmartAlarmClock.kicad_sch]
2026-08-01 hardware: add discrete carrier-PCB schematic (separate project)
    New stand-alone KiCad project SmartAlarmClock_discrete: a carrier board where the
    YD-ESP32-S3 dev board (J1) and MAX7219 matrix module (J2) plug in via headers.
    On-board discretes: DS3231 RTC with supercap backup (VBAT trickle-charged
    +3V3 -> R9 -> Schottky -> supercap, no coin cell), BSS138 x3 level shifter with
    10k pull-ups, BS170 buzzer driver + buzzer, touch-electrode pad, decoupling.
    All real stock-library symbols; ERC 0 errors / 0 warnings.
    Render to PNG and link it from hardware/README.md under PCB & enclosure. The
    existing block/hybrid schematic (SmartAlarmClock) is left untouched.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
    [SmartAlarmClock_discrete.kicad_pcb, SmartAlarmClock_discrete.kicad_sch]
2026-08-01 hardware: tidy discrete schematic layout
    Move ref/value of vertical passives (R/C) to the side so they no longer overlap
    the vertical global-label net names. Align the three level-shifter channels,
    group the RTC + supercap section, and pull the whole sheet closer together.
    Re-render the PNG. ERC still 0/0.
    [SmartAlarmClock_discrete.kicad_sch]
2026-08-08 firmware: add 3 MB app partition table (debug build exceeds 1 MB default)
    The Rust std debug image is ~1.6 MB, over the default 1 MB factory
    partition. Add partitions.csv (3 MB app, fits 4 MB flash; board has 16 MB)
    and pass --partition-table to the cargo runner so `cargo run` flashes it.
    [partitions.csv]
2026-08-08 test(firmware): add hwtest example — standalone hardware self-test
    Flash with `cargo run --example hwtest` to exercise the bench peripherals
    independently of the full firmware: onboard WS2812 cycle, buzzer beep,
    I2C bus scan (expects DS3231 @ 0x68), and a MAX7219 lamp test. Capacitive
    touch is left as a stub. Raw-probe level, not the real drivers.
    [hwtest.rs]
2026-08-08 test(firmware): play a melody in the buzzer self-test step
    Step 2 now plays "Twinkle Twinkle" by retuning the LEDC timer frequency
    per note (fixed 10-bit resolution keeps duty ~50%), replacing the beeps +
    LED fade. Duty-based volume was tried and dropped — on a magnetic buzzer
    the perceived loudness barely changes; real volume is a later digipot/amp.
    [hwtest.rs]
2026-08-08 hardware: initialize KiCad project settings (discrete carrier)
    KiCad populated the previously-empty {} project file with its default
    settings schema on open. No design changes.
2026-08-15 firmware: matrix time display + alarm melody, driven by shared state
    Add a MAX7219 32x8 matrix driver as a proper firmware module and wire it
    into the worker set, so the real clock shows the network-synced time.
    - display.rs: Matrix driver (font, framebuffer, FC-16 orientation, flush)
    ported from the clock example. The display worker reads shared
    {phase, now_secs} and renders HH:MM (blinking colon), or a blinking
    "--:--" while Phase::Syncing. The alarm core stays the sole time source.
    - buzzer.rs: port the per-note melody from the hwtest example (set_tone +
    play_melody). Ringing now plays a short rising alarm motif instead of a
    flat beep, re-checking phase between notes so snooze/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
    [buzzer.rs, clock.rs, display.rs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]
2026-08-15 test(firmware): add DS3231 RTC bench example
    Standalone I2C bench test for the DS3231 (SDA=GPIO8, SCL=GPIO9, 3V3, no
    level shifter). Probes 0x68, reports the OSF oscillator-stop flag, can
    program the time via RTC_SET='YYYY-MM-DD HH:MM:SS', and prints the ticking
    time once a second. Hand-rolled BCD + register access, no new deps.
    [rtc.rs]
2026-08-15 firmware: integrate DS3231 RTC — seed clock at boot, persist SNTP time
    Add rtc.rs and spawn it as a worker. At boot it reads the DS3231 and, if
    the time is valid (OSF clear + plausible), seeds the system clock so the
    display shows the time within ~1s instead of waiting for WiFi+SNTP. Once
    the system clock is valid it writes back to the RTC on boot and hourly,
    keeping the RTC disciplined to network time.
    RTC contents are UTC (system clock is UTC; TZ renders local for display).
    Hand-rolled BCD + register access; unix<->date via gmtime_r and a
    days-from-civil helper. No new dependencies. Verified on hardware: boot
    seed at ~0.7s, SNTP correction, hourly write-back.
    Also note in the rtc examp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
    [main.rs, rtc.rs]
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2026-08-15 docs: move HA integration to its own HACS repo, dedupe monorepo
    The custom integration now lives in MartBent/homeassistant-smart-alarm-clock
    (custom_components at root for HACS). Remove the duplicated copy under
    software/homeassistant/custom_components and replace its README with a
    pointer; update the root and software READMEs to link the HACS repo.
    [SmartAlarmClock_discrete.kicad_sch]
2026-08-15 hardware: rename SmartAlarmClock -> _prototype and rebuild as the decided first board
    Rename the KiCad project SmartAlarmClock -> SmartAlarmClock_prototype and rebuild
    its schematic as the decided first board (2026-08-15): a carrier where the ESP32-S3
    dev board (J1), MAX7219 matrix (J2), and DS3231 RTC module (J3, ZS-042) plug in via
    headers, and the board carries only the easy discrete glue — BSS138 x3 level shifter
    (+10k pull-ups), BS170 buzzer driver, touch pad (J4), and decoupling. The hard/
    high-risk blocks (ESP32 RF/antenna, MAX7219 routing) stay swappable modules; RTC and
    touch run natively at 3.3 V so only CS/DIN/CLK cross the shifter. ERC 0/0.
    Re-render the PNG and reframe the RE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
    [SmartAlarmClock.kicad_sch, SmartAlarmClock_prototype.kicad_pcb, SmartAlarmClock_prototype.kicad_sch]
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2026-08-15 hardware: redraw prototype schematic as grouped functional blocks
    Reorganize the prototype carrier schematic into labeled, boxed functional blocks
    (Dev Board, Decoupling, Level Shifter, RTC/Matrix module headers, Buzzer, Touch)
    like a real hand-drawn sheet. Power symbols for the rails, net labels for
    cross-block signals, all wires strictly horizontal/vertical, labels placed to the
    right of vertical wires / above horizontal ones, connector part-values hidden. ERC 0/0.
    [SmartAlarmClock_prototype.kicad_sch]
2026-11-10 Fix ponytail audit findings 1-11
    - alarm: a small backward clock step (DST fall-back, SNTP correction) no
    longer counts as a midnight wrap, which used to ring every enabled alarm
    - alarm: persist slots + display flag in NVS so they survive a reboot
    - alarm: stop an unattended alarm after 30 min (as if dismissed)
    - alarm: debug_assert self-check of the firing rule at boot
    - net: retry the boot WiFi join, reconnect when the link drops, and reboot
    out of the open setup AP after 10 min when creds are saved
    - net: require Content-Type: application/json on POSTs (blocks cross-site
    form posts from any web page); reject out-of-range alarm times
    - rtc: write the DS3231 only after an SNTP sync,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
